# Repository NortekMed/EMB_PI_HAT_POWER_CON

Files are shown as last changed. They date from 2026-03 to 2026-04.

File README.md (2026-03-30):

# PI-HAT Power Control

**Raspberry Pi HAT with Real-Time Clock and Power Management**

<p align="center">
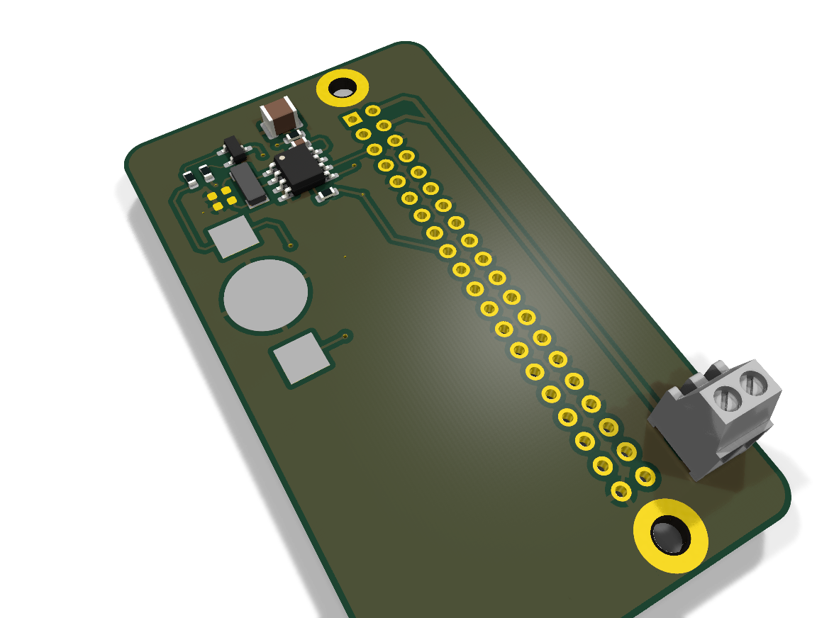
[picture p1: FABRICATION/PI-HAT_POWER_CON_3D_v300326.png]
3D PCB View
  
</p>

---

## 📋 Overview

This KiCad project provides a Raspberry Pi HAT featuring:
- **M41T0M6F** Serial Real-Time Clock with battery backup
- **32.768 kHz** crystal oscillator for precise timekeeping
- Power control and management circuitry
- Standard Raspberry Pi 40-pin GPIO header compatibility

**Company:** NortekMed  
**Version:** v300326 (2026-03-30)  
**Design Tool:** KiCad 10.0

---

## 📂 Project Structure

```
PI-HAT_POWER_CON/
├── DOCUMENTATION/
│   └── datasheet/           # Component datasheets (11 components)
├── FABRICATION/
│   ├── GERBER_v300326.zip   # Manufacturing files (Gerber + drill)
│   └── PI-HAT_POWER_CON_3D_v300326.png
├── GERBER/                  # Individual Gerber layer files
├── MECHANICAL/              # Mechanical drawings and models
├── SCHEMATICS/              # Additional schematic resources
├── PI-HAT_POWER_CON.kicad_pcb    # PCB layout file
├── PI-HAT_POWER_CON.kicad_sch    # Schematic file
├── PI-HAT_POWER_CON.kicad_pro    # KiCad project file
└── NortekLogo.png
```

---

## 🔧 Key Components

| Component | Part Number | Description |
|---|---|---|
| **RTC** | M41T0M6F | STMicroelectronics Serial RTC |
| **Oscillator** | CC4V-T1A | 32.768 kHz crystal oscillator |
| **Diode** | BAT54C-7-F | Schottky diode array |
| **Battery Holder** | Keystone 3000 | CR1220 coin cell holder |
| **Connector** | 282834-2 | Terminal block |

---

## 📁 Manufacturing Files

**Production-ready Gerber files:**
- `FABRICATION/GERBER_v300326.zip` - Complete manufacturing package
  - Gerber layers (top, bottom, silkscreen, solder mask)
  - Drill files (PTH and NPTH)
  - Job report

**Component Documentation:**
- All datasheets available in `DOCUMENTATION/datasheet/`
- Bill of Materials with Farnell part numbers in schematic

---

## 🛠️ Technical Specifications

- **Board Type:** 2-layer PCB
- **Dimensions:** Standard Raspberry Pi HAT form factor
- **Mounting:** Compatible with Raspberry Pi mounting holes
- **Interface:** I2C for RTC communication
- **Power:** Operates from Raspberry Pi 3.3V/5V supply
- **Battery Backup:** CR1220 coin cell for RTC during power-off

---

## 🔋 Maintenance

### RTC Battery Replacement

The Real-Time Clock (M41T0M6F) requires a **CR1220 or CR1225 coin cell battery** to maintain accurate timekeeping when the Raspberry Pi is powered off.

**Battery Specifications:**
- **Type:** CR1220 or CR1225 Lithium coin cell (3V)
- **Holder:** Keystone 3000
- **Typical Lifespan:** 5-10 years (depending on usage)
- **Standby Current:** ~0.9 µA

**Replacement Procedure:**
1. Power off the Raspberry Pi and disconnect all cables
2. Gently press and release the battery from the Keystone 3000 holder
3. Insert new CR1220 or CR1225 battery with positive (+) side facing up
4. Verify battery orientation matches the polarity markings on the PCB
5. Reconnect and power on - box should be start with modem to update/set date

**⚠️ Important Notes:**
- Always use fresh, high-quality CR1220 or CR1225 batteries
- Do not force the battery into the holder
- Dispose of used batteries according to local regulations
- Battery backup only maintains RTC time; it does not power other circuits

---

## 📜 License

© 2026 NortekMed. All rights reserved.

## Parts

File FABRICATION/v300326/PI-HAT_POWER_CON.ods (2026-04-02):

Reference | Value | Qty | DNP
BAT1401 | Keystone-3000 | 1
C1401 | 100nF | 1
C1404 | 22uF | 1
D1401 | BAT54C-7-F | 1
IC1401 | M41T0M6 | 1
J101 | 282834-2 | 1
J102 | Raspberry_Pi_2x20_PTH_NoSilk | 1
OSC1401 | CC4V-T1A | 1
R1401 | 100K | 1
R1402 | 0R | 1
R1403,R1404 | 22R | 2

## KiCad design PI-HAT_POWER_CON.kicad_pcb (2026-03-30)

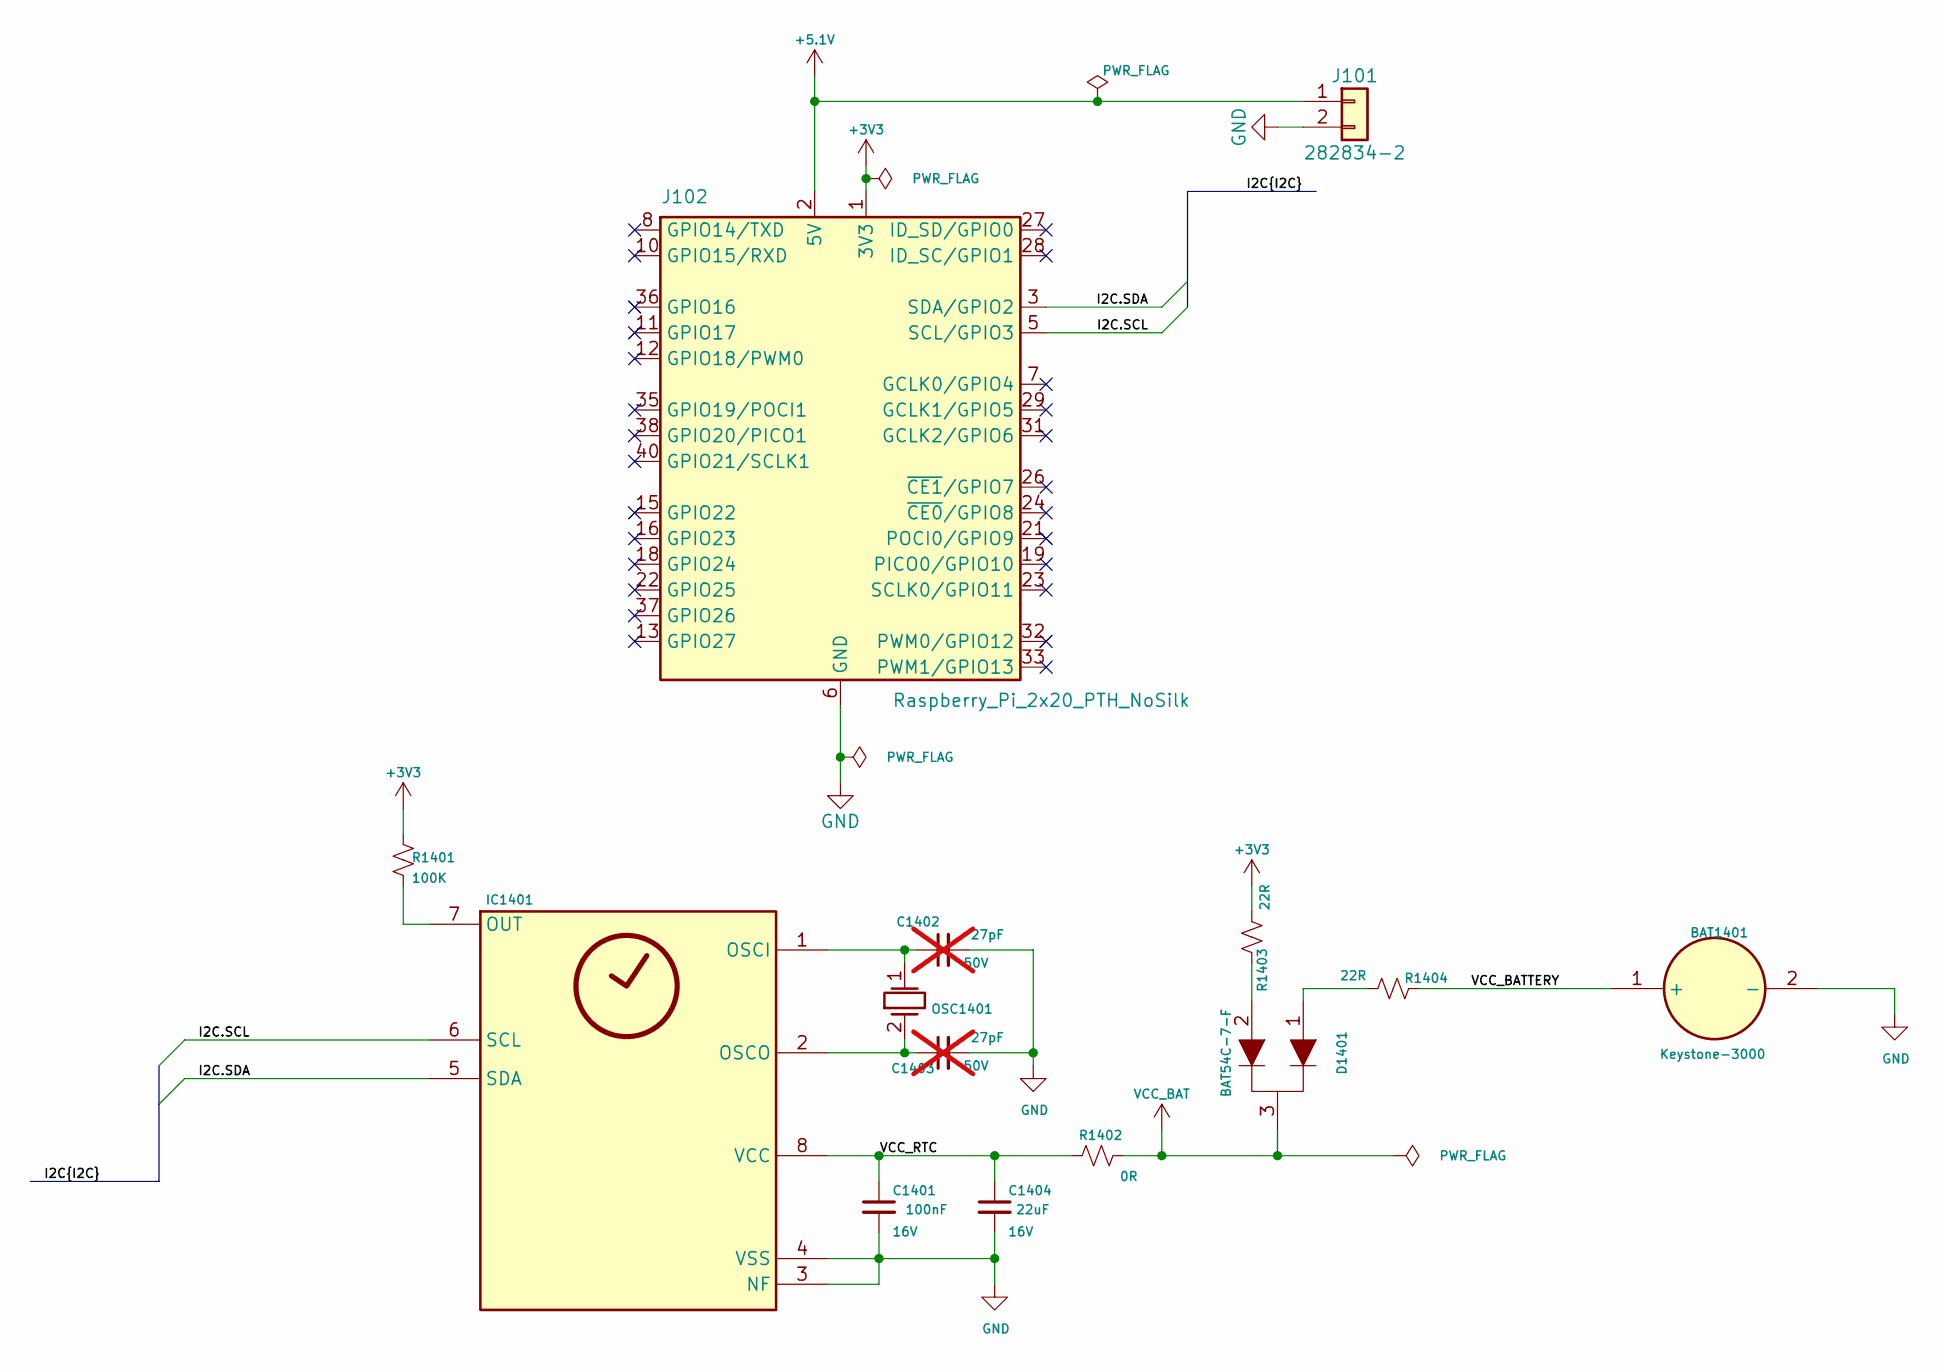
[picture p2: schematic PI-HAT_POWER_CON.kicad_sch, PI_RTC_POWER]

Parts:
BAT1401: Keystone-3000; T_Keystone_3000; mfr # 3000
C1401: 100nF; C_0603_1608Metric; TOLERANCE 10%; RATING 16V; mfr # VJ0603Y104KXJAT
C1402, C1403: 27pF; C_0603_1608Metric; TOLERANCE 5%; RATING 50V; mfr # *; not fitted
C1404: 22uF; C_1210_3225Metric; TOLERANCE 10%; RATING 16V; mfr # C1210C226K4PACTU
D1401: BAT54C-7-F; SOT-23-3; mfr # BAT54-7-F
IC1401: M41T0M6; SOIC-8_3.9x4.9mm_P1.27mm; mfr # M41T0M6
J101: 282834-2; TE_282834-2; mfr # 282834-2
J102: Raspberry_Pi_2x20_PTH_NoSilk; Raspberry_Pi_HAT_CON
OSC1401: CC4V-T1A; T_MC_CC4V-T1A; TOLERANCE 30ppm; mfr # CC4V-T1A
R1401: 100K; R_0603_1608Metric; RATING 63mW; TOLERANCE 5%; mfr # CRGS0603J100K
R1402: 0R; R_0603_1608Metric; RATING 100mW; TOLERANCE 1%; mfr # MCMR06X000 PTL
R1403, R1404: 22R; R_0603_1608Metric; RATING 100mW; TOLERANCE 5%; mfr # CRCW060322R0JNEA

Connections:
+3V3: J102.1 (3V3), J102.17 (3V3), R1401.1, R1403.2
+5.1V: J101.1, J102.2 (5V), J102.4 (5V)
/I2C.SCL: IC1401.6 (SCL), J102.5 (SCL/GPIO3)
/I2C.SDA: IC1401.5 (SDA), J102.3 (SDA/GPIO2)
/VCC_BATTERY: BAT1401.1 (+), R1404.1
/VCC_RTC: C1401.1, C1404.1, IC1401.8 (VCC), R1402.1
GND: BAT1401.2 (-), C1401.2, C1402.2, C1403.2, C1404.2, IC1401.3 (NF), IC1401.4 (VSS), J101.2, J102.6 (GND), J102.9 (GND), J102.14 (GND), J102.20 (GND), J102.25 (GND), J102.30 (GND), J102.34 (GND), J102.39 (GND)
unnamed: D1401.1, R1404.2
unnamed: D1401.2, R1403.1
unnamed: C1402.1, IC1401.1 (OSCI), OSC1401.1 (OSC1)
unnamed: C1403.1, IC1401.2 (OSCO), OSC1401.2 (OSC2)
unnamed: IC1401.7 (OUT), R1401.2
VCC_BAT: D1401.3, R1402.2

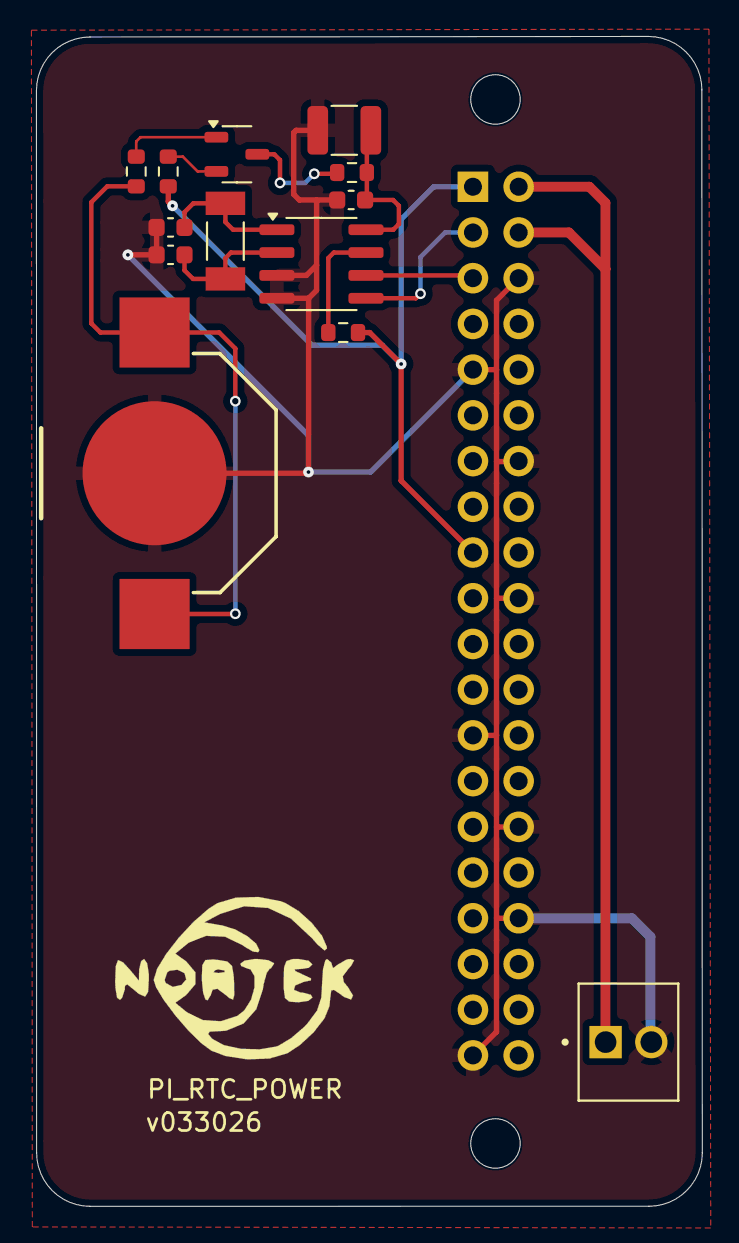
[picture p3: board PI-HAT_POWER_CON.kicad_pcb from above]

Board: 2 copper layers, 37.0 x 65.0 mm, 14 parts (0 on the bottom side), 13 nets.

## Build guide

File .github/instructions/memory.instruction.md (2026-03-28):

---
applyTo: '**'
---

# Memory Segments by Topic

## 1. Git & Project Setup
- Analyzed project folder; initial commit created, only tracking source files and omitting generated, backup, and temp files using a tailored KiCad .gitignore.
- Tagged v030226.
- Created and pushed to new GitHub repo NortekMed/EMB_PI_HAT_POWER_CON. Branches: master, RTC3231.

## 2. RTC Components (Hardware & Software)
- Explained that the M41T0M6 RTC is kernel-supported via rtc-m41t80; integration on Pi3 is simple:
  - Enable I2C, use overlay 'dtoverlay=i2c-rtc,m41t80' in /boot/config.txt, connect RTC, reboot.
- M41T0M6 support is built into modern Linux/Raspberry Pi OS; no extra driver needed beyond enabling overlay and I2C.
- Addition of the M41T0M6 to the KiCad project was committed and pushed to branch RTC3231.

## 3. Workflow & Command Guidance
- Provided precise shell/git commands for git auth, repo creation, branches, and tagging.
- Advised on GitHub CLI login/token clarification.
- Covered steps for pushing commits, managing .gitignore, and integrating new components in a collaborative workflow.

---
# Instructions
- To suppress or forget one segment (topic), specify its topic title (e.g., "suppress RTC Components (Hardware & Software)").
- Memory can be updated or expanded in this file as the project or discussion evolves.

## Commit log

2026-03-27 Initial commit: add KiCad project and essential files, omitting generated and ignored files
    [PI-HAT_POWER_CON.kicad_pcb, PI-HAT_POWER_CON.kicad_sch]
2026-03-27 Add M41T0M6 RTC component to project schematic, PCB, and project settings
    [PI-HAT_POWER_CON.kicad_pcb, PI-HAT_POWER_CON.kicad_sch]
2026-03-28 Route PCB: Complete all nets, DRC clear, power and RTC connectivity verified
    [PI-HAT_POWER_CON.kicad_pcb, PI-HAT_POWER_CON.kicad_sch]
2026-03-30 Update README with project documentation and add 3D render v300326
    - Replace template README with comprehensive project documentation
    - Add maintenance section with RTC battery replacement procedure (CR1220/CR1225)
    - Include 3D isometric render of PCB (1176x872px, high quality)
    - Document key components, manufacturing files, and technical specifications
    - Reference GERBER_v300326.zip and component datasheets
    - Add project structure and NortekMed branding
2026-03-30 prepare for v300326 production
    [PI-HAT_POWER_CON.kicad_pcb, PI-HAT_POWER_CON.kicad_sch]
2026-04-02 remove ignoring FABRICATION
    [PI-HAT_POWER_CON.ods]
